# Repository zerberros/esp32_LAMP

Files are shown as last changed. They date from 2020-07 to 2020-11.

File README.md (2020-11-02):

# esp32_LAMP
A led lamp controlled by ESP32 

## To Do

- [x] Design PCB
- [x] Mount components
- [x] Make the encapsulation with epoxy resin
- [ ] Write firmware
- [ ] Enjoy

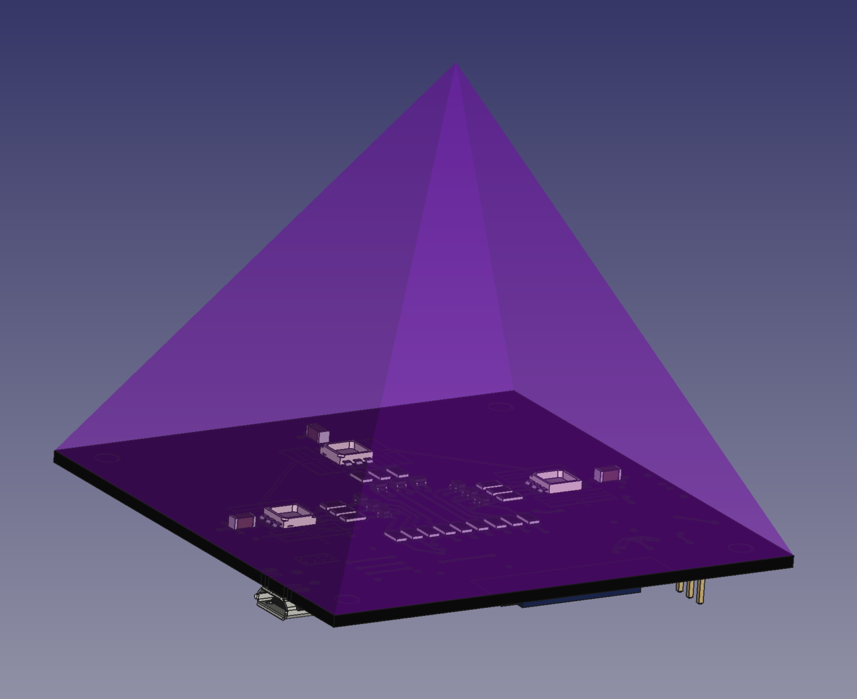
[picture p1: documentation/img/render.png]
render


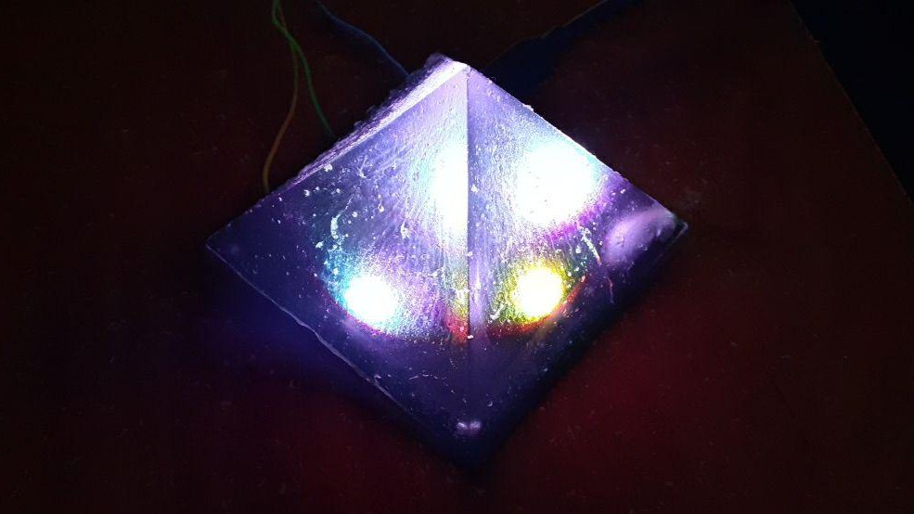
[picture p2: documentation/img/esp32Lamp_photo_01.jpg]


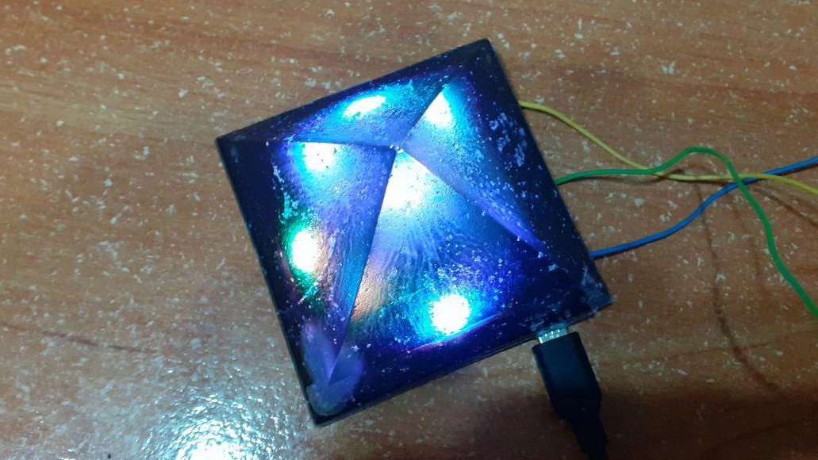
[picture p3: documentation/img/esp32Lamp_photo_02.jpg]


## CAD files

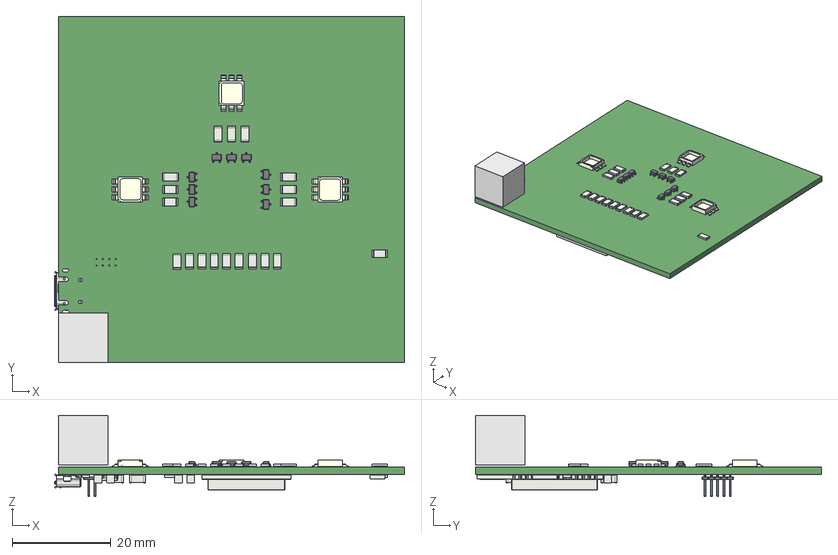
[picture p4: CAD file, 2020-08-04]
kicad_files/3D_models/ESP32_lamp.FCStd
70.8 x 70.0 x 16.5 mm
Cubo

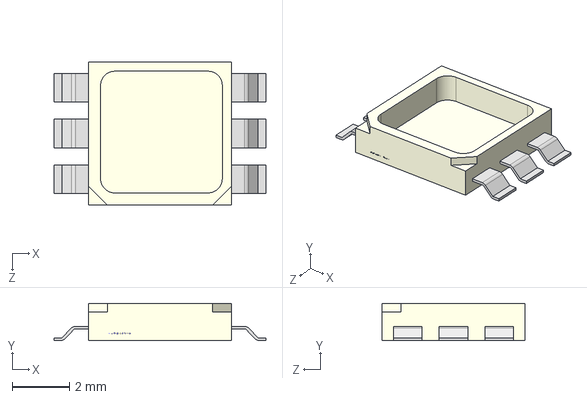
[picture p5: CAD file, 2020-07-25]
kicad_files/3D_models/AAAF5051-05.STEP
7.40 x 1.30 x 5.00 mm

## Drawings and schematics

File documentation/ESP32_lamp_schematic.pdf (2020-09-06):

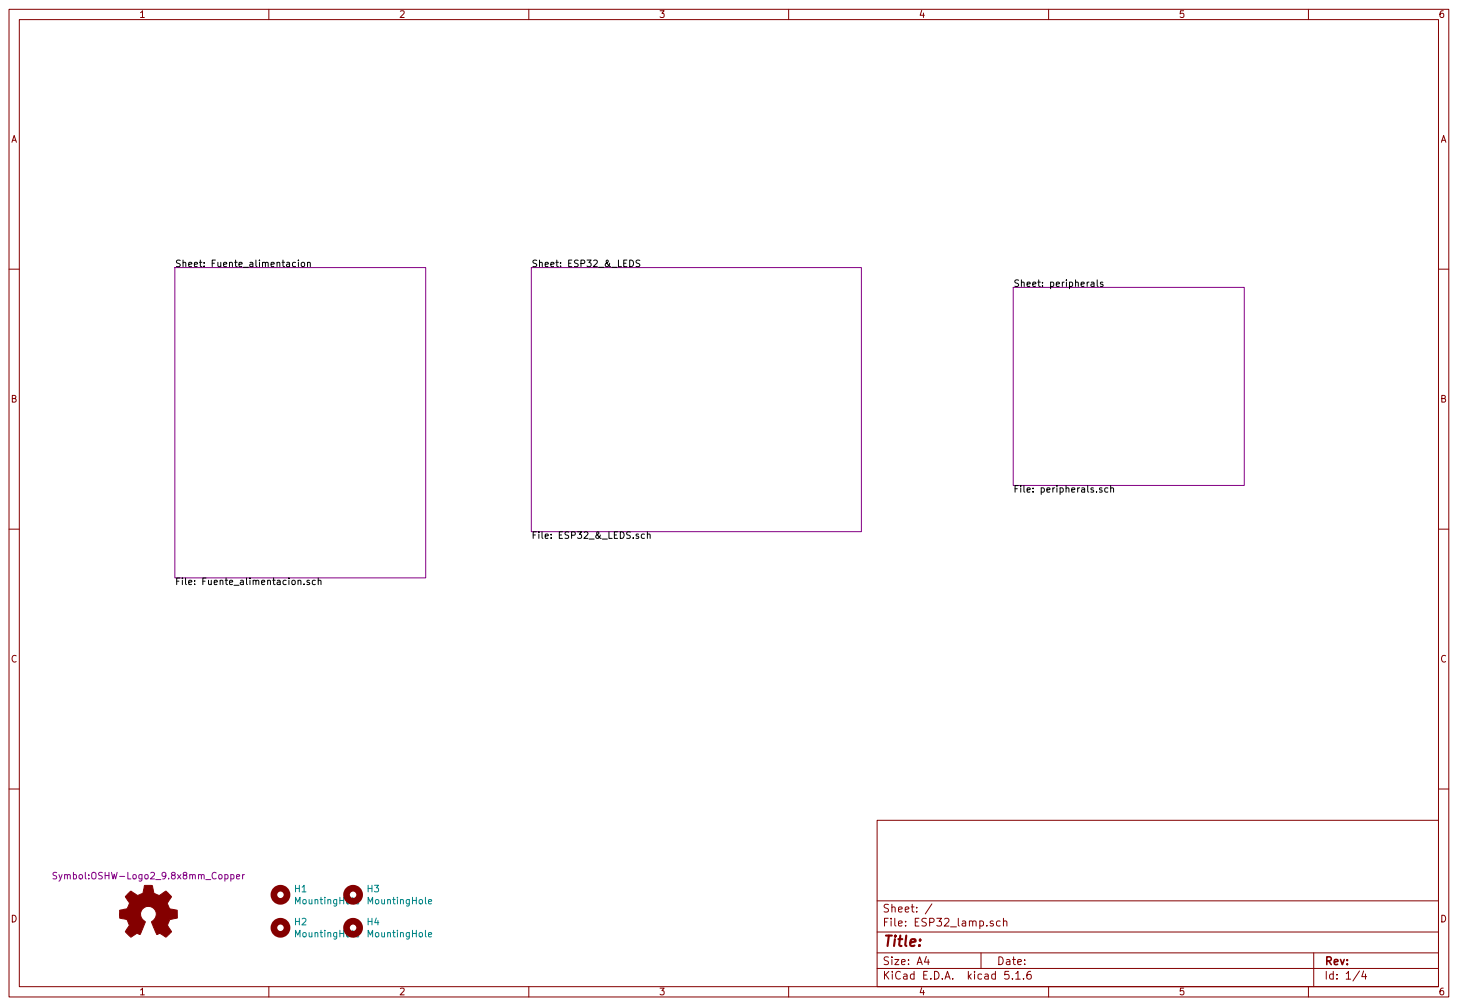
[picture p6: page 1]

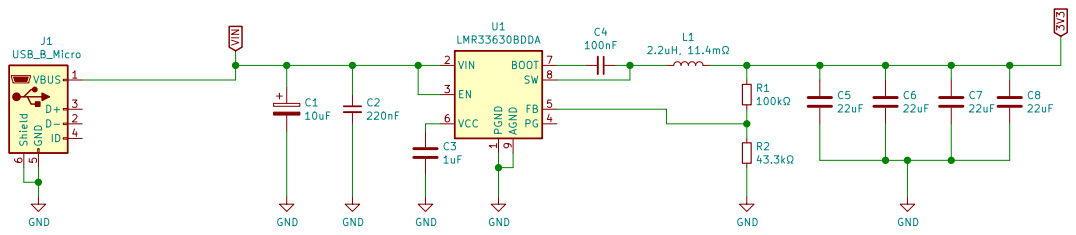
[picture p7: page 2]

1 VIN 2 EN 3 PG 4 FB 5 VCC 6 BOOT 7 SW 8 AGND

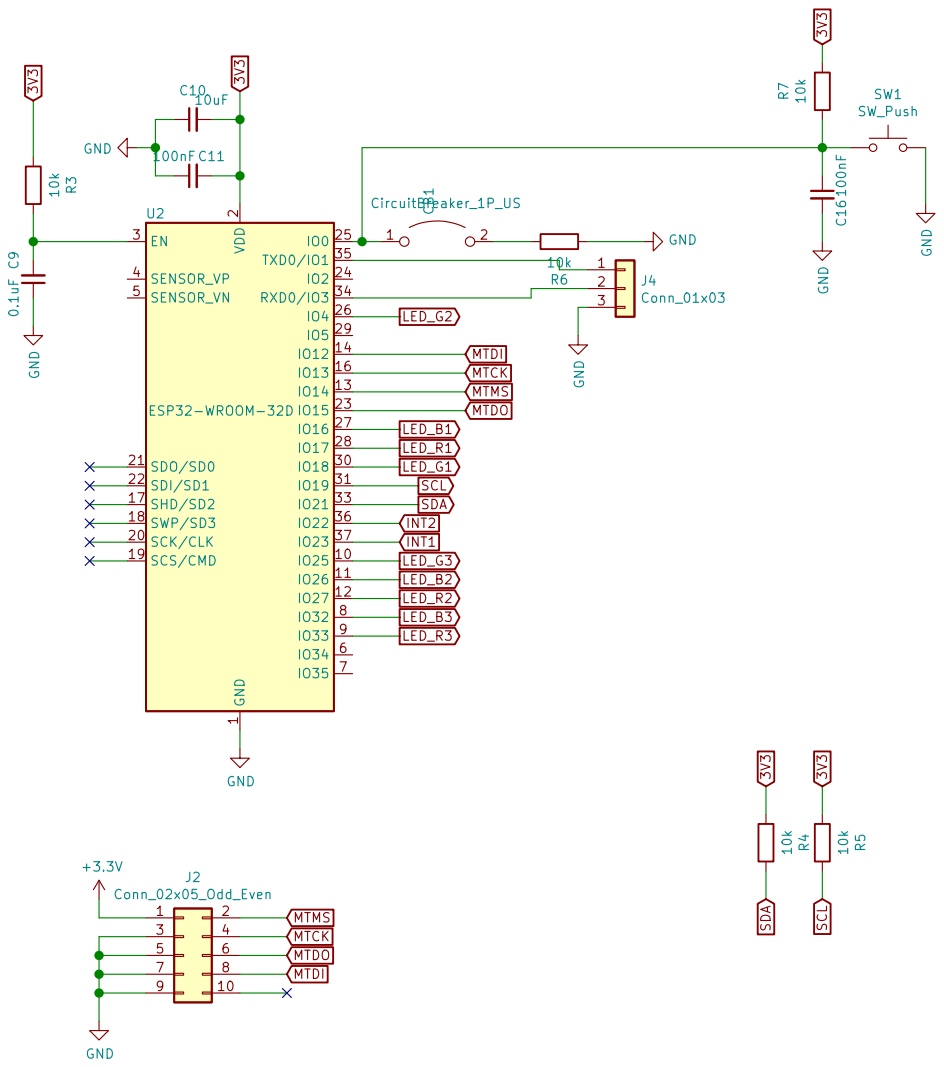
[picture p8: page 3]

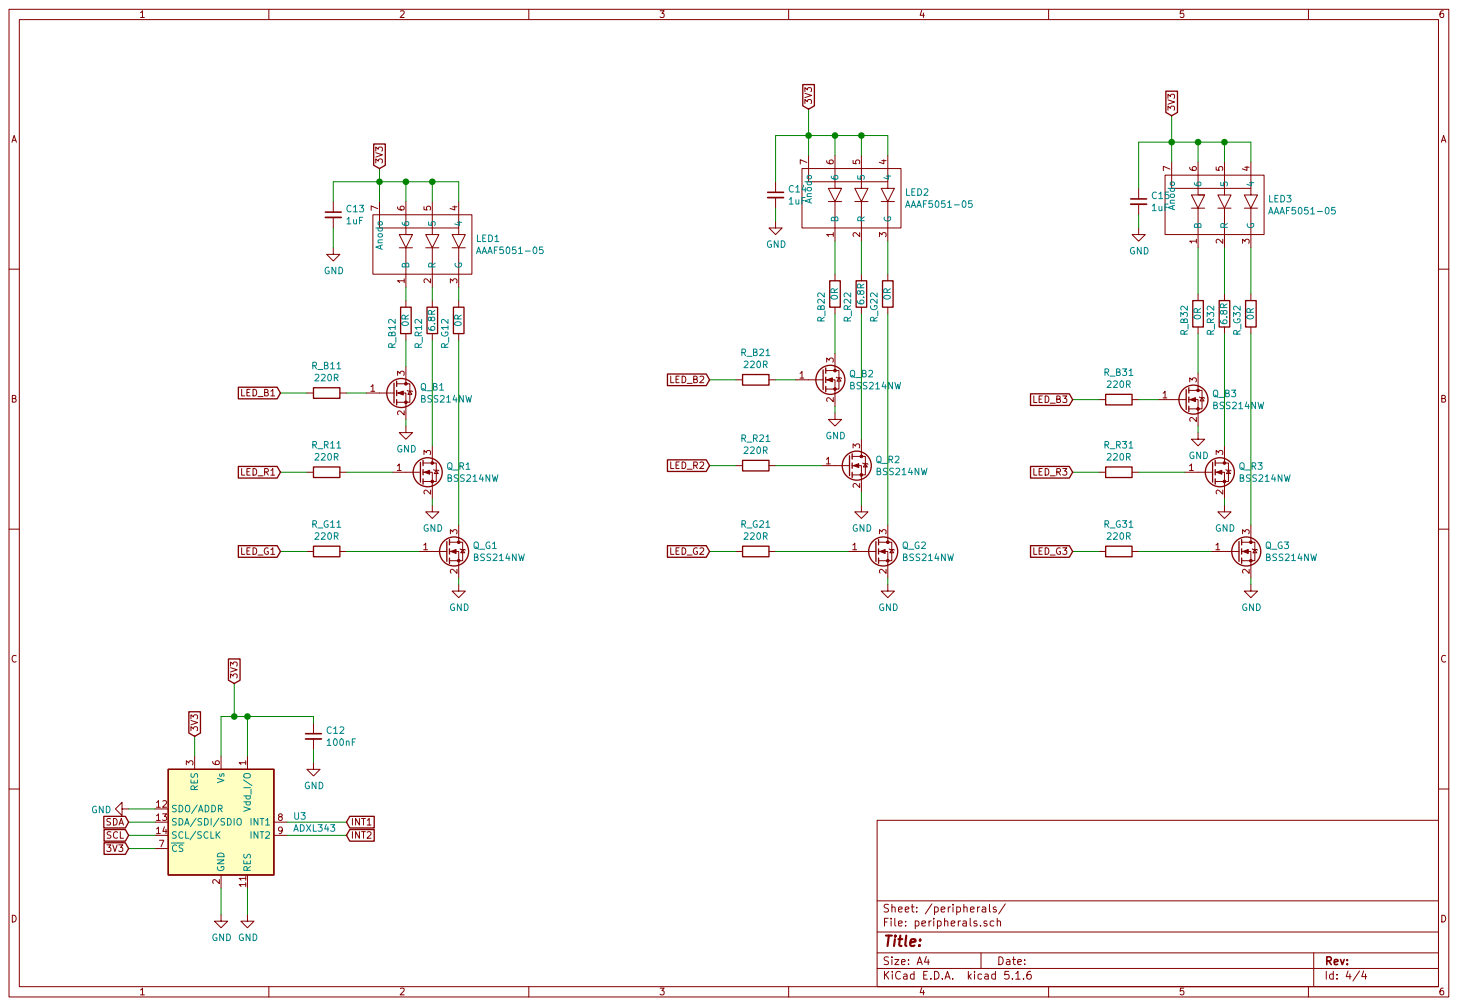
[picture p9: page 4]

1 RES 11 SDO/ADDR 12 SDA/SDI/SDIO 13 SCL/SCLK 14 GND

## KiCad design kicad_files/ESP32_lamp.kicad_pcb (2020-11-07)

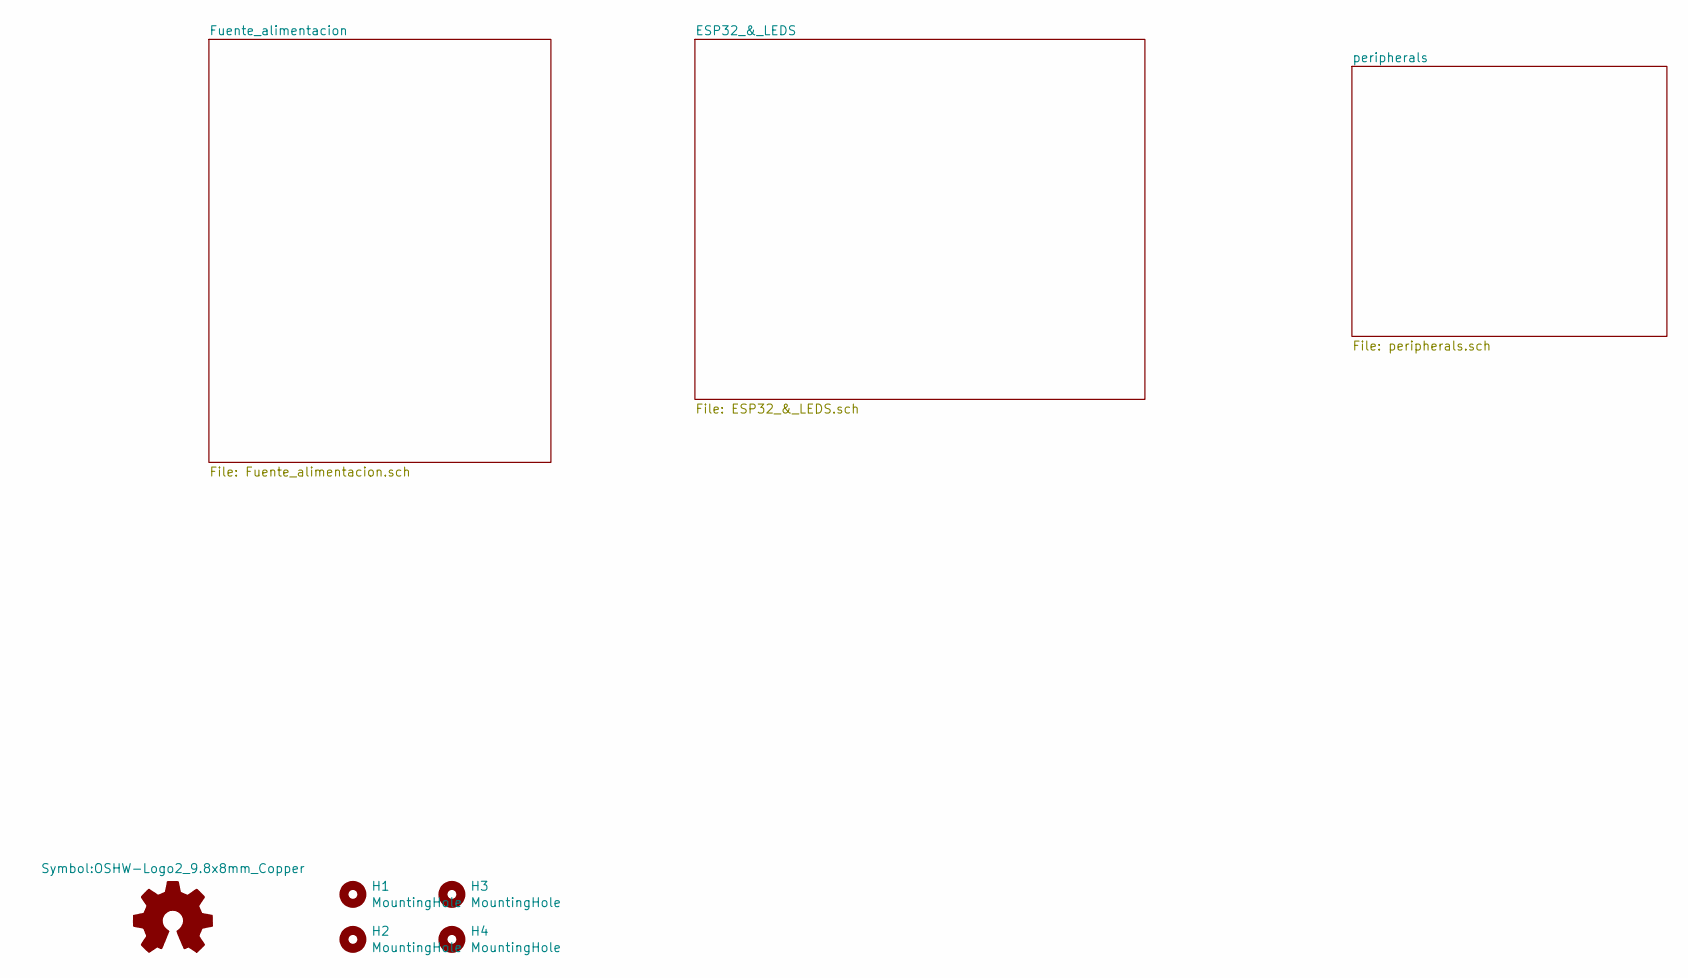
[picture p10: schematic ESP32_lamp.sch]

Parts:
H1, H2, H3, H4: MountingHole; MountingHole_3.2mm_M3_ISO7380; MPN SJ-5003 (BLACK)

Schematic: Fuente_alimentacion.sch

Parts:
C1: 10uF; C_1206_3216Metric
C2: 220nF; C_1206_3216Metric
C3: 1uF; C_1206_3216Metric
C4: 100nF; C_1206_3216Metric
C5, C6, C7, C8: 22uF; C_1206_3216Metric
J1: USB_B_Micro; USB_Micro-AB_Molex_47590-0001; MPN 47590-0001
L1: 2.2uH, 11.4mΩ; L_Taiyo-Yuden_MD-5050; MPN TYS50402R2N-10
R1: 100kΩ; R_1206_3216Metric
R2: 43.3kΩ; R_1206_3216Metric
U1: LMR33630BDDA; Texas_HSOP-8-1EP_3.9x4.9mm_P1.27mm_ThermalVias; MPN LMR33630BDDAR

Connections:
3V3: C5.1, C6.1, C7.1, C8.1, L1.2, R1.1; also elsewhere on the board
GND: C1.2, C2.2, C3.2, C5.2, C6.2, C7.2, C8.2, J1.5, J1.6, R2.2, U1.1 (PGND), U1.9 (AGND); also elsewhere on the board
unnamed: C3.1, U1.6 (VCC)
unnamed: C4.1, L1.1, U1.8 (SW)
unnamed: C4.2, U1.7 (BOOT)
unnamed: R1.2, R2.1, U1.5 (FB)
VIN: C1.1, C2.1, J1.1, U1.2 (VIN), U1.3 (EN)

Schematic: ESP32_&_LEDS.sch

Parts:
C9: 0.1uF; C_1206_3216Metric
C10: 10uF; C_1206_3216Metric
C11, C16: 100nF; C_1206_3216Metric
CB1: CircuitBreaker_1P_US; SolderJumper-2_P1.3mm_Open_TrianglePad1.0x1.5mm
J2: Conn_02x05_Odd_Even; PinHeader_2x05_P1.27mm_Vertical_SMD; MPN M50-3610542R
J4: Conn_01x03; PinHeader_1x03_P2.54mm_Vertical_SMD_Pin1Left
R3, R4, R5, R6, R7: 10k; R_1206_3216Metric
SW1: SW_Push; Panasonic_EVQPUJ_EVQPUA; MPN EVQ-PUJ02K
U2: ESP32-WROOM-32D; ESP32-WROOM-32; MPN ESP32-WROOM-32D

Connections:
3V3: C10.2, C11.2, R3.2, R4.2, R5.2, R7.1, U2.2 (VDD); also elsewhere on the board
+3V3: J2.1
GND: C9.1, C10.1, C11.1, C16.2, J2.3, J2.5, J2.7, J2.9, J4.3, R6.2, SW1.1, U2.1 (GND), U2.15 (GND), U2.38 (GND), U2.39 (GND); also elsewhere on the board
INT1: U2.37 (IO23); also elsewhere on the board
INT2: U2.36 (IO22); also elsewhere on the board
LED_B1: U2.27 (IO16); also elsewhere on the board
LED_B2: U2.11 (IO26); also elsewhere on the board
LED_B3: U2.8 (IO32); also elsewhere on the board
LED_G1: U2.30 (IO18); also elsewhere on the board
LED_G2: U2.26 (IO4); also elsewhere on the board
LED_G3: U2.10 (IO25); also elsewhere on the board
LED_R1: U2.28 (IO17); also elsewhere on the board
LED_R2: U2.12 (IO27); also elsewhere on the board
LED_R3: U2.9 (IO33); also elsewhere on the board
MTCK: J2.4, U2.16 (IO13)
MTDI: J2.8, U2.14 (IO12)
MTDO: J2.6, U2.23 (IO15)
MTMS: J2.2, U2.13 (IO14)
unnamed: C9.2, R3.1, U2.3 (EN)
unnamed: C16.1, CB1.1, R7.2, SW1.2, U2.25 (IO0)
unnamed: CB1.2, R6.1
unnamed: J4.1, U2.35 (TXD0/IO1)
unnamed: J4.2, U2.34 (RXD0/IO3)
SCL: R5.1, U2.31 (IO19); also elsewhere on the board
SDA: R4.1, U2.33 (IO21); also elsewhere on the board

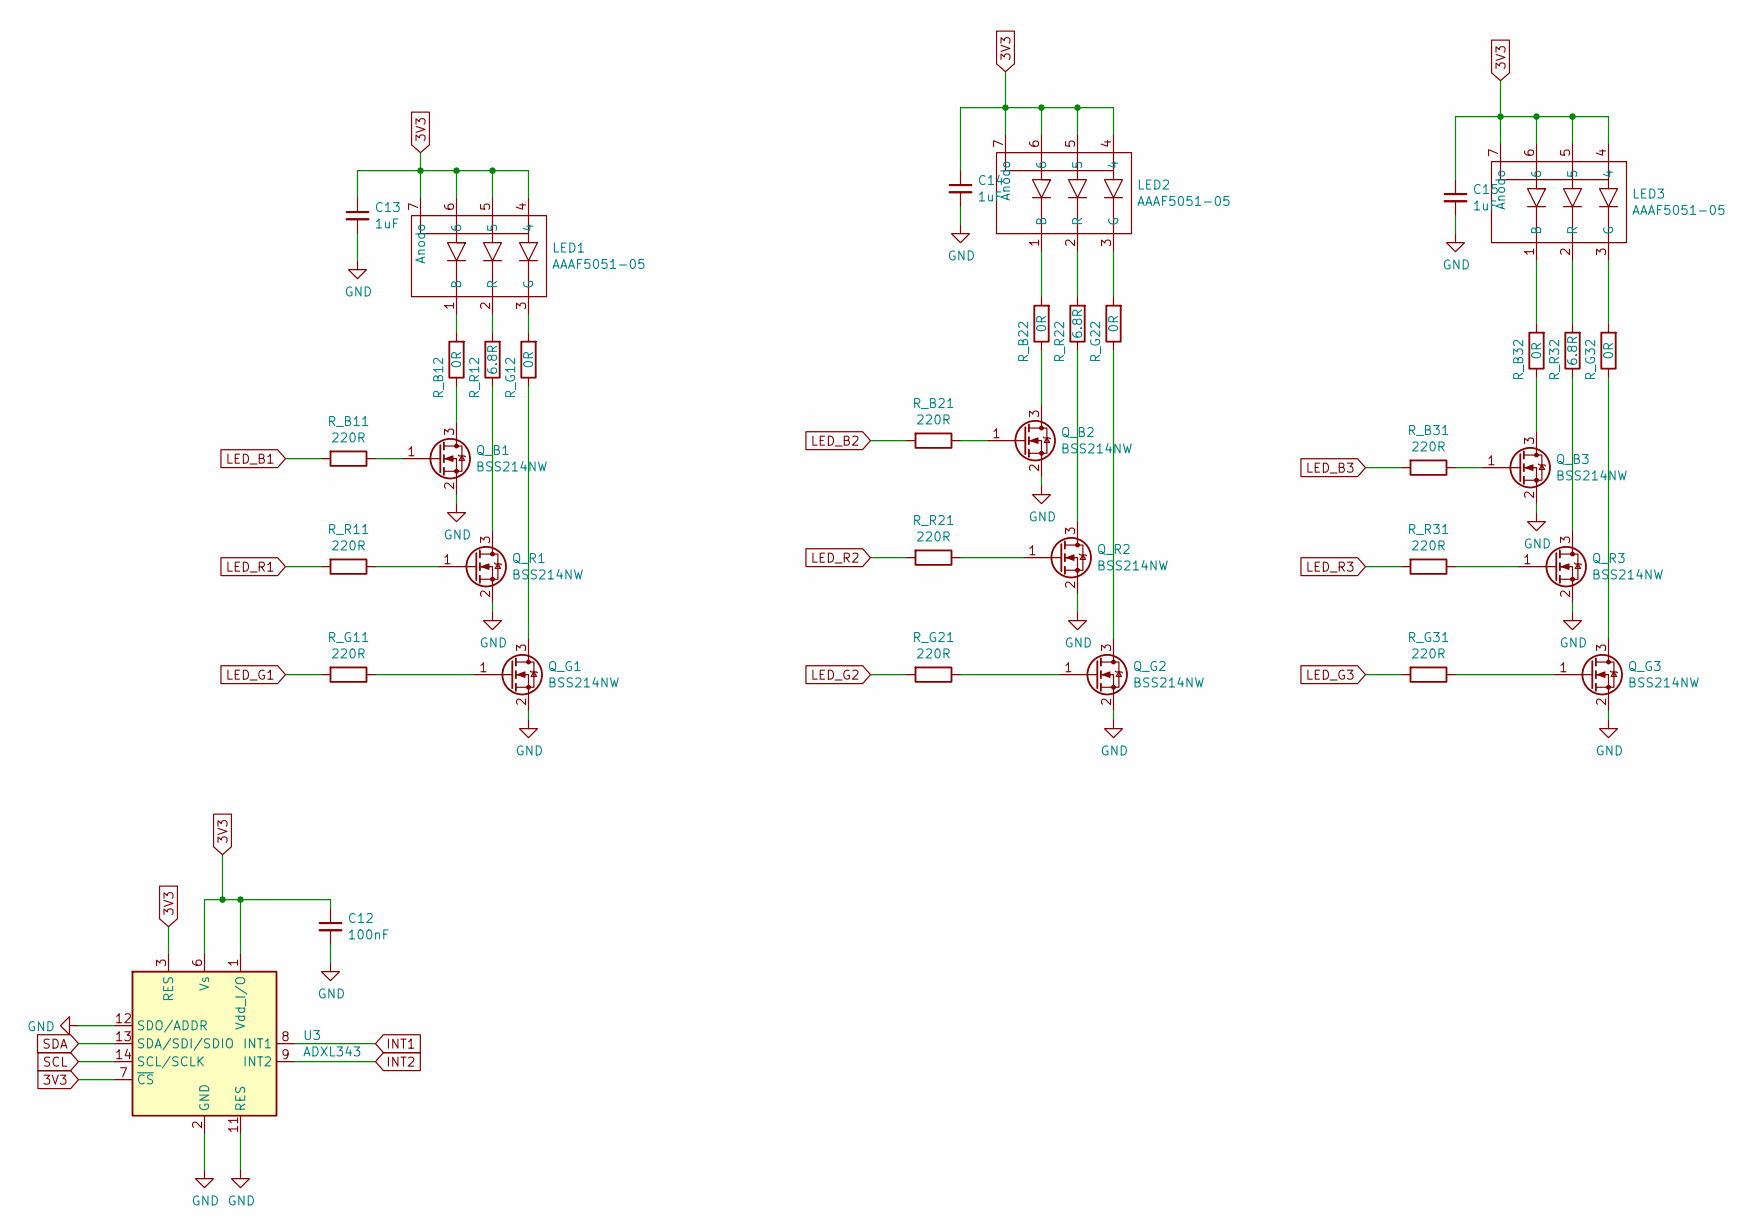
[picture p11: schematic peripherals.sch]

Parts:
C12: 100nF; C_1206_3216Metric
C13, C14, C15: 1uF; C_1206_3216Metric
LED1, LED2, LED3: AAAF5051-05; kinbright-AAAF5051-05_MOD; MPN AAAF5051-05
Q_B1, Q_B2, Q_B3: BSS214NW; SOT-323_SC-70; MPN BSS214NWH6327XTSA1
Q_G1, Q_G2, Q_G3: BSS214NW; SOT-323_SC-70; MPN BSS214NWH6327XTSA1
Q_R1, Q_R2, Q_R3: BSS214NW; SOT-323_SC-70; MPN BSS214NWH6327XTSA1
R_B11, R_B21, R_B31: 220R; R_1206_3216Metric
R_B12, R_B22, R_B32: 0R; R_1206_3216Metric
R_G11, R_G21, R_G31: 220R; R_1206_3216Metric
R_G12, R_G22, R_G32: 0R; R_1206_3216Metric
R_R11, R_R21, R_R31: 220R; R_1206_3216Metric
R_R12, R_R22, R_R32: 6.8R; R_1206_3216Metric; MPN SG73P2BTTD6R8J
U3: ADXL343; LGA-14_3x5mm_P0.8mm_LayoutBorder1x6y; MPN ADXL343BCCZ

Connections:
3V3: C12.1, C13.1, C14.1, C15.1, LED1.4, LED1.5, LED1.6, LED1.7 (Anodo), LED2.4, LED2.5, LED2.6, LED2.7 (Anodo), LED3.4, LED3.5, LED3.6, LED3.7 (Anodo), U3.1 (Vdd_I/O), U3.3 (RES), U3.6 (Vs), U3.7 (~CS); also elsewhere on the board
GND: C12.2, C13.2, C14.2, C15.2, Q_B1.2 (S), Q_B2.2 (S), Q_B3.2 (S), Q_G1.2 (S), Q_G2.2 (S), Q_G3.2 (S), Q_R1.2 (S), Q_R2.2 (S), Q_R3.2 (S), U3.2 (GND), U3.4 (GND), U3.5 (GND), U3.11 (RES), U3.12 (SDO/ADDR); also elsewhere on the board
INT1: U3.8 (INT1); also elsewhere on the board
INT2: U3.9 (INT2); also elsewhere on the board
LED_B1: R_B11.2; also elsewhere on the board
LED_B2: R_B21.2; also elsewhere on the board
LED_B3: R_B31.2; also elsewhere on the board
LED_G1: R_G11.2; also elsewhere on the board
LED_G2: R_G21.2; also elsewhere on the board
LED_G3: R_G31.2; also elsewhere on the board
LED_R1: R_R11.2; also elsewhere on the board
LED_R2: R_R21.2; also elsewhere on the board
LED_R3: R_R31.2; also elsewhere on the board
unnamed: LED1.1 (B), R_B12.2
unnamed: LED1.2 (R), R_R12.2
unnamed: LED1.3 (G), R_G12.2
unnamed: LED2.1 (B), R_B22.2
unnamed: LED2.2 (R), R_R22.2
unnamed: LED2.3 (G), R_G22.2
unnamed: LED3.1 (B), R_B32.2
unnamed: LED3.2 (R), R_R32.2
unnamed: LED3.3 (G), R_G32.2
unnamed: Q_B1.1 (G), R_B11.1
unnamed: Q_B1.3 (D), R_B12.1
unnamed: Q_B2.1 (G), R_B21.1
unnamed: Q_B2.3 (D), R_B22.1
unnamed: Q_B3.1 (G), R_B31.1
unnamed: Q_B3.3 (D), R_B32.1
unnamed: Q_G1.1 (G), R_G11.1
unnamed: Q_G1.3 (D), R_G12.1
unnamed: Q_G2.1 (G), R_G21.1
unnamed: Q_G2.3 (D), R_G22.1
unnamed: Q_G3.1 (G), R_G31.1
unnamed: Q_G3.3 (D), R_G32.1
unnamed: Q_R1.1 (G), R_R11.1
unnamed: Q_R1.3 (D), R_R12.1
unnamed: Q_R2.1 (G), R_R21.1
unnamed: Q_R2.3 (D), R_R22.1
unnamed: Q_R3.1 (G), R_R31.1
unnamed: Q_R3.3 (D), R_R32.1
SCL: U3.14 (SCL/SCLK); also elsewhere on the board
SDA: U3.13 (SDA/SDI/SDIO); also elsewhere on the board

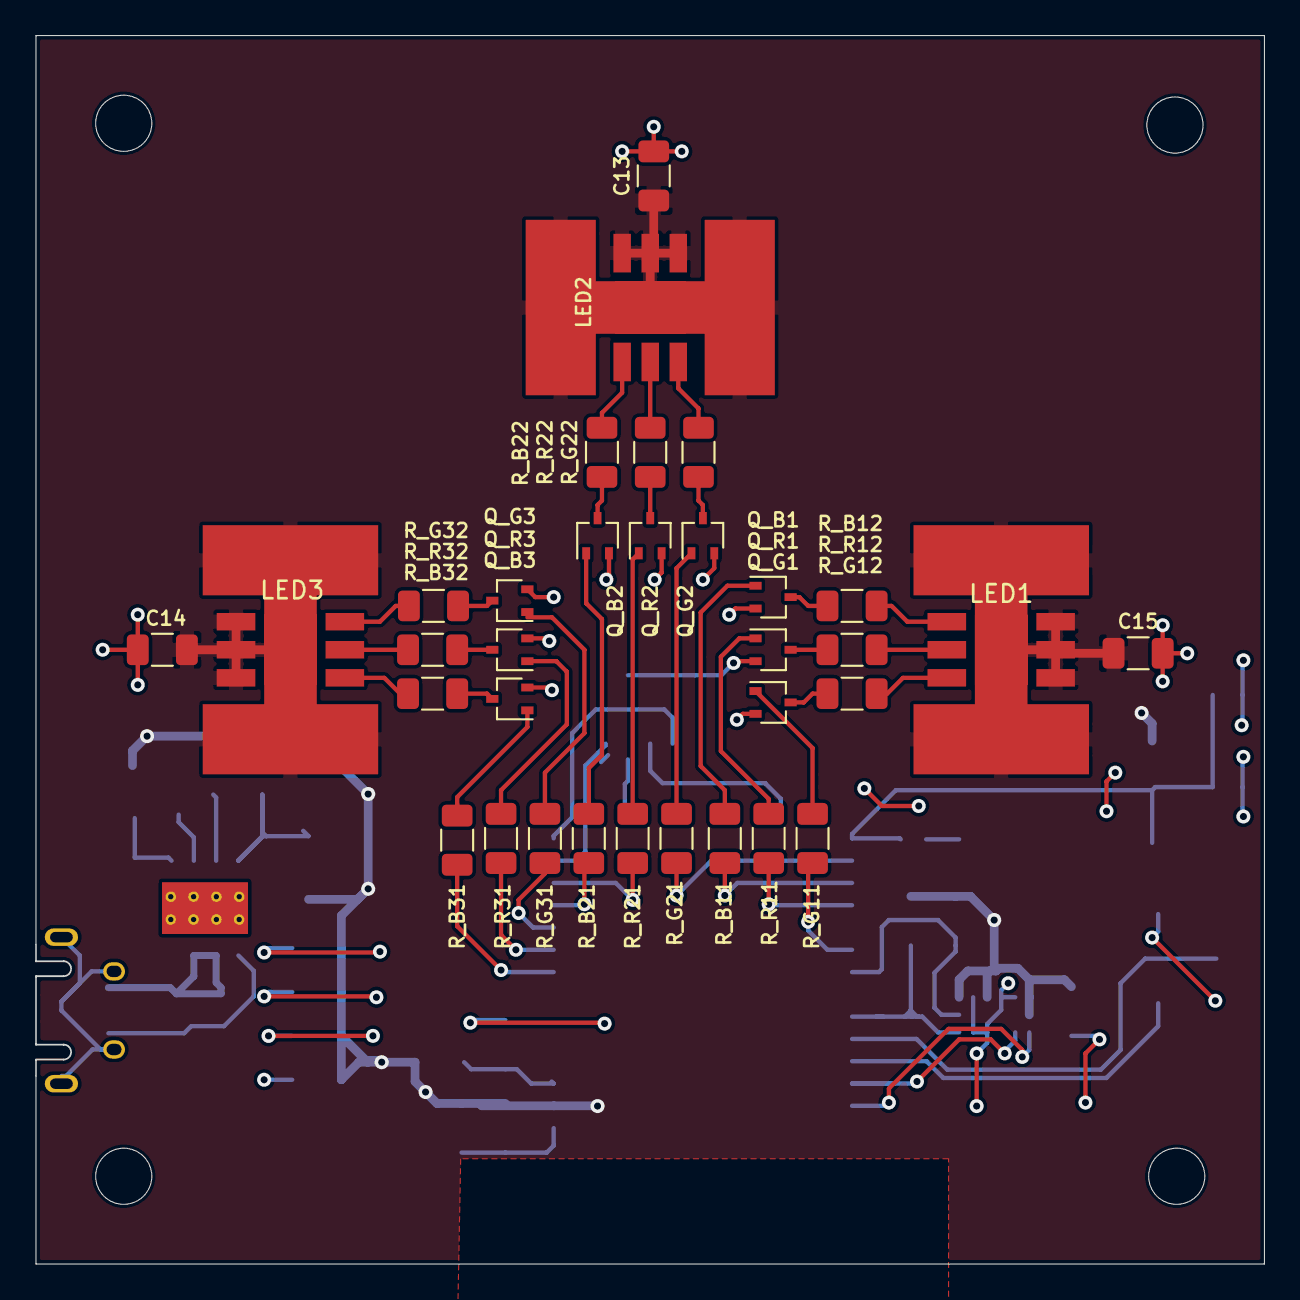
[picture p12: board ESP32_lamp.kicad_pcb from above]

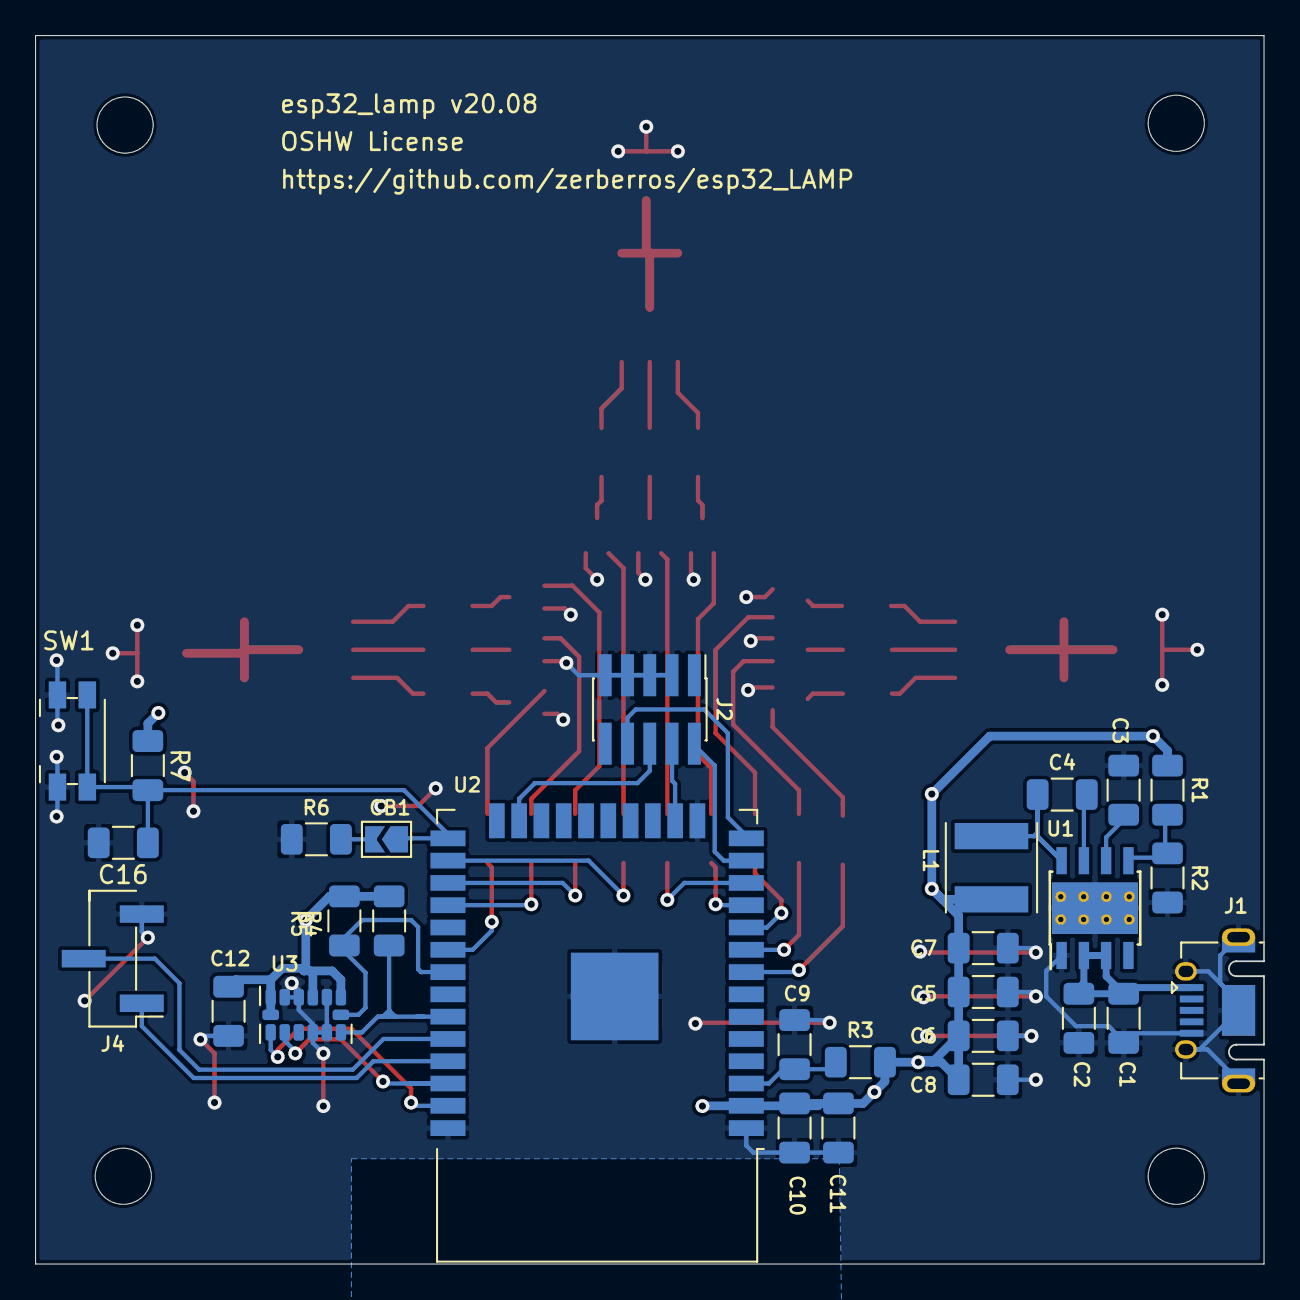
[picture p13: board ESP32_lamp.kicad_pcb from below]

Board: 2 copper layers, 70.0 x 70.0 mm, 66 parts (29 on the bottom side), 56 nets.

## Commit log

2020-06-15 update repositories
    [ESP32_lamp.kicad_pcb, ESP32_lamp.sch]
2020-07-25 update schem
    [3220-10-0100-00.step, 3220-10-0100.igs, AAAF5051-05.STEP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]
2020-08-17 Release Candidate 0
    [ESP32_lamp.kicad_pcb, ESP32_lamp.sch, Fuente_alimentacion.sch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]
2020-08-17 Added backSilkscreen
    [ESP32_lamp.kicad_pcb]
2020-08-28 WIP Release Candidate 1
    [ESP32_&_LEDS.sch, peripherals.sch]
2020-09-03 Added Gerber files
    [ESP32_lamp-B_SilkS.gbr, ESP32_lamp-F_Cu.gbr, ESP32_lamp-F_SilkS.gbr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]
2020-09-03 rename kicad folder
    [3220-10-0100-00.step, 3220-10-0100.igs, AAAF5051-05.STEP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]
2020-09-03 Added bom file
2020-09-03 clean 3D folder
    [3220-10-0100-00.step, 3220-10-0100.igs]
2020-09-06 Added schematics
2020-11-07 Update MPN attributes && BOM file
    [ESP32_&_LEDS.sch, ESP32_lamp.kicad_pcb, ESP32_lamp.sch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]
